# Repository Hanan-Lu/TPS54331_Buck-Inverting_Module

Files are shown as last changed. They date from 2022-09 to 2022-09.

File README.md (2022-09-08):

# 简介

> 本项目是一个基于TPS54331的DC-DC转换器，通过修改一颗电阻的安装位置，可以配置为正压输出或负压输出。
> 
> 本项目初始设计参数为输出5V/1A或-5V/500mA，如有其它参数需求用户可自行计算电感及补偿网络器件参数。

# 使用

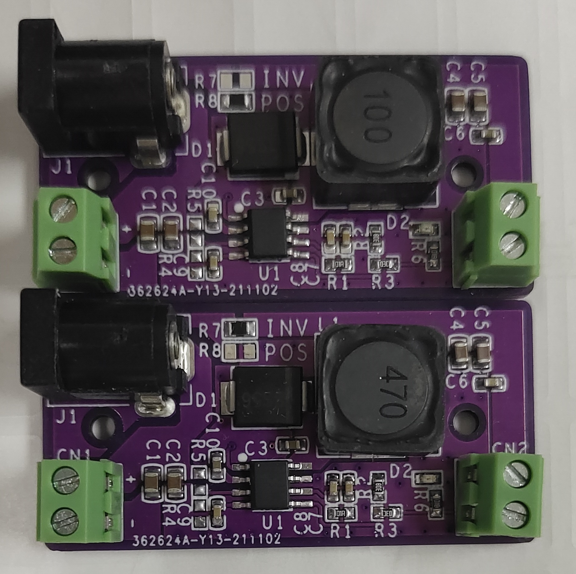
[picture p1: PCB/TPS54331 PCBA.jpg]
实物图


> 如图，上面模块配置为正压输出(安装R8，不安装R7)，即普通的Buck模式；
> 
> 下面的模块配置为反相输出(安装R7，不安装R8)，即Inventor-Buck模式；
> 
> ***<font color=red>注意，反相输出时最大输入电压=28V-输出电压绝对值</font>***

# 原理

> 原理请参见Document目录下的"*Using a buck converter in an inverting.pdf*",本处不在赘述。

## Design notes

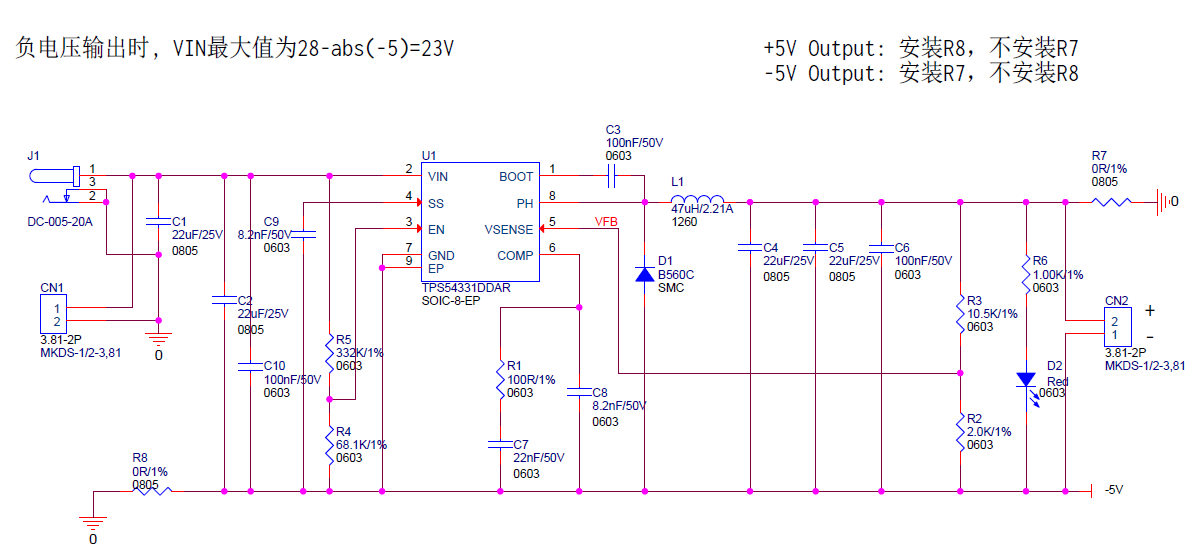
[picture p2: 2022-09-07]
SCH/TPS54331 SCH.png

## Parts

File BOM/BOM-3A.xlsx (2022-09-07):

Item Number | Part Number | Value | Description | Footprint | Part Reference | Quantity | Manufacturer1 | Manufacturer1 PN | Manufacturer1 Datasheet
1 | 01.02.000362 | 22uF/25V | GP MLCC, 22uF, 25V ±20%, X5R, EIA 0805 | 0805 | C1,C2,C4,C5 | 4 | Samaung | CL21A226MAYNNNE | http://weblib.samsungsem.com/mlcc/mlcc-ec-data-sheet.do?partNumber=CL21A226MAYNNN
2 | 01.02.000134 | 100nF/50V | GP MLCC, 100nF, 50V, 10%, X7R, EIA 0603 | 0603 | C3,C6,C10 | 3 | Samaung | CL10B104KB8NNN | http://weblib.samsungsem.com/mlcc/mlcc-ec-data-sheet.do?partNumber=CL10B104KB8NNN
3 | 01.02.000113 | 1nF/50V | GP MLCC, 1nF, 50V, 10%, X7R, EIA 0603 | 0603 | C7 | 1 | Samaung | CL10B102KB8NNN | http://weblib.samsungsem.com/mlcc/mlcc-ec-data-sheet.do?partNumber=CL10B102KB8NNN
4 | 01.02.000619 | 10pF/50V | GP MLCC, 10pF, 50V, ±10%, C0G, EIA 0603 | 0603 | C8 | 1 | Samaung | CL10C100KB8NNN | http://weblib.samsungsem.com/mlcc/mlcc-ec-data-sheet.do?partNumber=CL10C100KB8NNN
5 | 01.02.001313 | 8.2nF/50V | GP MLCC, 8.2nF, 50V, 10%, X7R, EIA 0603 | 0603 | C9 | 1 | Samaung | CL10B822KB8NFN | http://weblib.samsungsem.com/mlcc/mlcc-ec-data-sheet.do?partNumber=CL10B822KB8NFN
6 | 01.12.000349 | MKDS-1/2-3,81 | PCB terminal block, Screw connection, 2P, 13.5A, 200V, Horizon, Green, 3.81mm | 3.81-2P | CN1,CN2 | 2 | Phoenix | MKDS 1/ 2-3,81 | https://www.phoenixcontact.com/online/portal/cn/?uri=pxc-oc-itemdetail:pid=1727010
7 | 01.05.000348 | B560C | Schottky Barrier Rectifier Diode, B560C, VR=60V, IO=5A, SMC | SMC | D1 | 1 | Diodes | B560C-13-F | https://www.diodes.com/assets/Datasheets/ds13012.pdf
8 | 01.06.000003 | Red | LED, 顶部发光, 清澈透光型, Red, 631nm, VF=2V, EIA 0603, Height=0.8mm | 0603 | D2 | 1 | LITEON | LTST-C190KRKT | https://optoelectronics.liteon.com/upload/download/DS-22-99-0151/LTST-C190KRKT.PDF
9 | 01.12.000347 | DC-005-20A | DC Power Jack, Outer 6.4mm, Inner 2.0mm, THT, Right angled | DC-005-3P | J1 | 1 | HRO | DC-005-20A | http://www.krhro.com/uploads/soft/180314/1-1P314135239.pdf
10 | 01.04.000181 | 8.2uH/6.25A | SMT Shielded Power Inductor, 8.2uH, 6.25A, 20mΩ, 12.5x12.5x6.0mm | 1260 | L1 | 1 | Würth | 744771008 | https://www.we-online.com/catalog/datasheet/744771008.pdf
11 | 01.01.001040 | 63.4K/1% | THICK FILM CHIP RESISTORS, 63.4k, 1%, 1/10W, EIA 0603 | 0603 | R1 | 1 | RALEC | RTT036342FTP | https://www.ralec.com/upload/media/product/file/IE-SP-007.pdf
12 | 01.01.000896 | 2.0K/1% | THICK FILM CHIP RESISTORS, 2.0k, 1%, 1/10W, EIA 0603 | 0603 | R2 | 1 | RALEC | RTT032001FTP | https://www.ralec.com/upload/media/product/file/IE-SP-007.pdf
13 | 01.01.000965 | 10.5K/1% | THICK FILM CHIP RESISTORS, 10.5k, 1%, 1/10W, EIA 0603 | 0603 | R3 | 1 | RALEC | RTT031052FTP | https://www.ralec.com/upload/media/product/file/IE-SP-007.pdf
14 | 01.01.001043 | 68.1K/1% | THICK FILM CHIP RESISTORS, 68.1k, 1%, 1/10W, EIA 0603 | 0603 | R4 | 1 | RALEC | RTT036812FTP | https://www.ralec.com/upload/media/product/file/IE-SP-007.pdf
15 | 01.01.001109 | 332K/1% | THICK FILM CHIP RESISTORS, 332k, 1%, 1/10W, EIA 0603 | 0603 | R5 | 1 | RALEC | RTT033323FTP | https://www.ralec.com/upload/media/product/file/IE-SP-007.pdf
16 | 01.01.000867 | 1.00K/1% | THICK FILM CHIP RESISTORS, 1.00k, 1%, 1/10W, EIA 0603 | 0603 | R6 | 1 | RALEC | RTT031001FTP | https://www.ralec.com/upload/media/product/file/IE-SP-007.pdf
17 | 01.01.002285 | 0R/1% | THICK FILM CHIP RESISTORS, 0R, 1%, 2.5A, EIA 0805 | 0805 | R7,R8 | 2 | RALEC | RTT050000FTP | https://www.ralec.com/upload/media/product/file/IE-SP-007.pdf
18 | 01.09.000066 | TPS54331DDAR | Step Down DC-DC Converter, TPS54331DDAR , 3.5-28V, 3A, VFB:0.8V SO8-PowerPAD | SOIC-8-EP | U1 | 1 | TI | TPS54331DDAR | https://www.ti.com.cn/cn/lit/ds/symlink/tps54331.pdf

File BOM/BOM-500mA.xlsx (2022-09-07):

Item Number | Part Number | Value | Description | Footprint | Part Reference | Quantity | Manufacturer1 | Manufacturer1 PN | Manufacturer1 Datasheet
1 | 01.02.000362 | 22uF/25V | GP MLCC, 22uF, 25V ±20%, X5R, EIA 0805 | 0805 | C1,C2,C4,C5 | 4 | Samaung | CL21A226MAYNNNE | http://weblib.samsungsem.com/mlcc/mlcc-ec-data-sheet.do?partNumber=CL21A226MAYNNN
2 | 01.02.000134 | 100nF/50V | GP MLCC, 100nF, 50V, 10%, X7R, EIA 0603 | 0603 | C3,C6,C10 | 3 | Samaung | CL10B104KB8NNN | http://weblib.samsungsem.com/mlcc/mlcc-ec-data-sheet.do?partNumber=CL10B104KB8NNN
3 | 01.02.000128 | 22nF/50V | GP MLCC, 22nF, 50V, 10%, X7R, EIA 0603 | 0603 | C7 | 1 | Samaung | CL10B223KB8NNN | http://weblib.samsungsem.com/mlcc/mlcc-ec-data-sheet.do?partNumber=CL10B223KB8NNN
4 | 01.02.001313 | 8.2nF/50V | GP MLCC, 8.2nF, 50V, 10%, X7R, EIA 0603 | 0603 | C8,C9 | 2 | Samaung | CL10B822KB8NFN | http://weblib.samsungsem.com/mlcc/mlcc-ec-data-sheet.do?partNumber=CL10B822KB8NFN
5 | 01.12.000349 | MKDS-1/2-3,81 | PCB terminal block, Screw connection, 2P, 13.5A, 200V, Horizon, Green, 3.81mm | 3.81-2P | CN1,CN2 | 2 | Phoenix | MKDS 1/ 2-3,81 | https://www.phoenixcontact.com/online/portal/cn/?uri=pxc-oc-itemdetail:pid=1727010
6 | 01.05.000348 | B560C | Schottky Barrier Rectifier Diode, B560C, VR=60V, IO=5A, SMC | SMC | D1 | 1 | Diodes | B560C-13-F | https://www.diodes.com/assets/Datasheets/ds13012.pdf
7 | 01.06.000003 | Red | LED, 顶部发光, 清澈透光型, Red, 631nm, VF=2V, EIA 0603, Height=0.8mm | 0603 | D2 | 1 | LITEON | LTST-C190KRKT | https://optoelectronics.liteon.com/upload/download/DS-22-99-0151/LTST-C190KRKT.PDF
8 | 01.12.000347 | DC-005-20A | DC Power Jack, Outer 6.4mm, Inner 2.0mm, THT, Right angled | DC-005-3P | J1 | 1 | HRO | DC-005-20A | http://www.krhro.com/uploads/soft/180314/1-1P314135239.pdf
9 | 01.04.000190 | 47uH/2.21A | SMT Shielded Power Inductor, 47uH, 2.21A, 75mΩ, 12.5x12.5x6.0mm | 1260 | L1 | 1 | Würth | 744771147 | https://www.we-online.com/catalog/datasheet/744771147.pdf
10 | 01.01.000771 | 100R/1% | THICK FILM CHIP RESISTORS, 100R, 1%, 1/10W, EIA 0603 | 0603 | R1 | 1 | RALEC | RTT031000FTP | https://www.ralec.com/upload/media/product/file/IE-SP-007.pdf
11 | 01.01.000896 | 2.0K/1% | THICK FILM CHIP RESISTORS, 2.0k, 1%, 1/10W, EIA 0603 | 0603 | R2 | 1 | RALEC | RTT032001FTP | https://www.ralec.com/upload/media/product/file/IE-SP-007.pdf
12 | 01.01.000965 | 10.5K/1% | THICK FILM CHIP RESISTORS, 10.5k, 1%, 1/10W, EIA 0603 | 0603 | R3 | 1 | RALEC | RTT031052FTP | https://www.ralec.com/upload/media/product/file/IE-SP-007.pdf
13 | 01.01.001043 | 68.1K/1% | THICK FILM CHIP RESISTORS, 68.1k, 1%, 1/10W, EIA 0603 | 0603 | R4 | 1 | RALEC | RTT036812FTP | https://www.ralec.com/upload/media/product/file/IE-SP-007.pdf
14 | 01.01.001109 | 332K/1% | THICK FILM CHIP RESISTORS, 332k, 1%, 1/10W, EIA 0603 | 0603 | R5 | 1 | RALEC | RTT033323FTP | https://www.ralec.com/upload/media/product/file/IE-SP-007.pdf
15 | 01.01.000867 | 1.00K/1% | THICK FILM CHIP RESISTORS, 1.00k, 1%, 1/10W, EIA 0603 | 0603 | R6 | 1 | RALEC | RTT031001FTP | https://www.ralec.com/upload/media/product/file/IE-SP-007.pdf
16 | 01.01.002285 | 0R/1% | THICK FILM CHIP RESISTORS, 0R, 1%, 2.5A, EIA 0805 | 0805 | R7,R8 | 2 | RALEC | RTT050000FTP | https://www.ralec.com/upload/media/product/file/IE-SP-007.pdf
17 | 01.09.000066 | TPS54331DDAR | Step Down DC-DC Converter, TPS54331DDAR , 3.5-28V, 3A, VFB:0.8V SO8-PowerPAD | SOIC-8-EP | U1 | 1 | TI | TPS54331DDAR | https://www.ti.com.cn/cn/lit/ds/symlink/tps54331.pdf

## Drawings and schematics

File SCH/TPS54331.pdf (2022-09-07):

# +5V Output: 安安R8，不安安R7 -5V Output: 安安R7，不安安R8

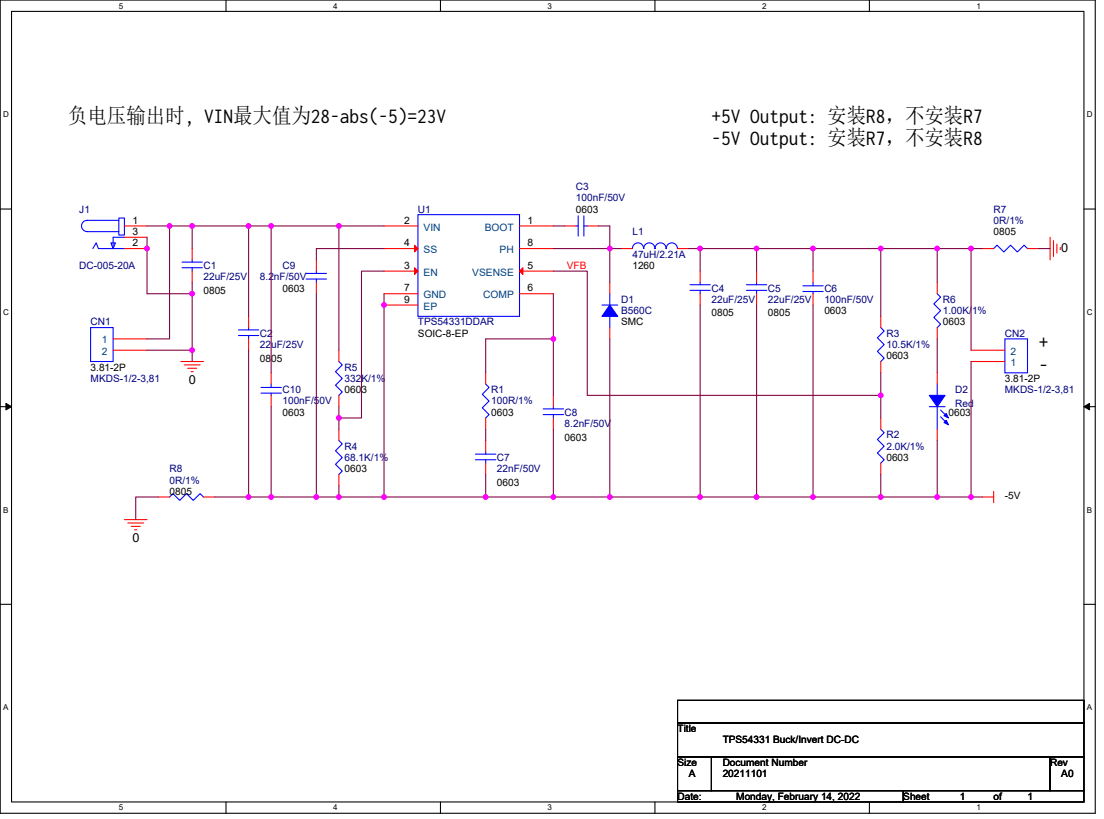
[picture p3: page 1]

TPS54331 Buck/Invert DC-DC

Size Size Size A A A | Document Number Document Number Document Number 20211101 20211101 20211101 | Rev Rev Rev A0 A0 A0

Date: Date: Date: Monday, February 14, 2022 Monday, February 14, 2022 Monday, February 14, 2022 | Sheet Sheet Sheet 1 1 1 of of of 1 1 1
